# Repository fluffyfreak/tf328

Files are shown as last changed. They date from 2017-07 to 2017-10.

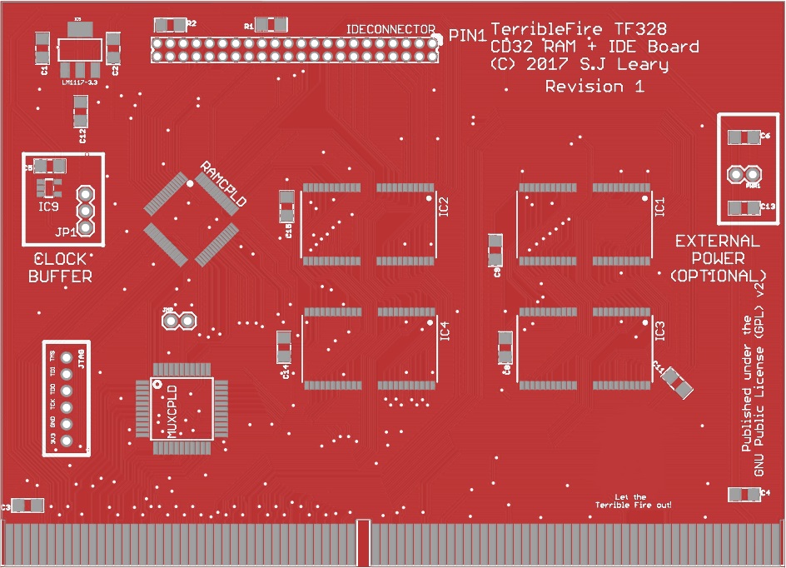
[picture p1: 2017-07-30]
docs/tf328_rev1.jpg

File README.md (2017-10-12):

# TF328 Revision 1

An 8mb Fast RAM + IDE Board for the CD32.

Known Issues: 

1. Your CF Card MUST be 3.3/5V tolerant as some of the control signals are 3.3V.

A prototype version was built and this contains all the lessons learned from that prototype. 

This repository contains all the files needed to produce a copy of my IDE+RAM board.

The CPLDs Required are 1 x XC9572XL-10VQ64 and 1 x XC9536XL-10VQG44C.  10ns "Commercial" version is fine.

Everything in this repository is released under the GNU GPLv2. You may create or base commercial PCBs from the work in this repository but you must make the sources for all derivative work available. I have noticed some forks have removed copyright notices. This is a breach of the GPL.

## Board Options

### Clock Buffer 

The clock buffer is a stabilty modification I added to buffer the clock due to slow rise times observed on other Amiga Hardware. It may not be required at all. If you decide not to add the clock buffer then you should jumper the middle pin of the CLOCKSEL jumper to the pin nearest the edge connector. If you wish to use the buffered clock you need to add IC9 and jumper the middle pin to the position nearest the IDE connector. If you wish to disable the board remove the jumper entirely.

### External Power

Jumper PWR1 is intended for use when bringing up the board so that the CPLDs can be programmed without inserting the card. It is not required after this unless you wish to use it to power other devices. 

### JMP Feature 

Jumper JMP is intended to trigger an NMI. This works via the MUXCPLD which detects the external pin being pulled HIGH and will pull IPL0-2 low until released. This feature is done synchronously to prevent glitches. It is intended for use with HRTMon. 

## Firmware / Requirements

  * Xilinx ISE, 14.7 (the final version - other versions may work but this is the one I support)
  * JTAG Adaptor

[For more information visit my channel](https://www.youtube.com/c/TerribleFire)

## License

This project and all the files contained are released under the GNU GPLv2. If you build a modified version of the board you must supply the end user with all the sources (this can be a web link).

# Bill of Materials

|Part | Value | Device | Package | Description |
|-----|---|---|---|---|
| R1 | 1K | RESISTOR1206 | 1206 | Resistors | 
| R2 | 1K | RESISTOR1206 | 1206 | Resistors | 
| C1 | 10uF | CAP_CERAMIC1206 | 1206 | Ceramic Capacitors | 
| C2 | 10uF | CAP_CERAMIC1206 | 1206 | Ceramic Capacitors | 
| C3 | 10uF | CAP_CERAMIC1206 | 1206 | Ceramic Capacitors | 
| C4 | 22uF | CAP_CERAMIC1206 | 1206 | Ceramic Capacitors | 
| C5 | 100nF | CAP_CERAMIC1206 | 1206 | Ceramic Capacitors | 
| C6 | 22uF | CAP_CERAMIC1206 | 1206 | Ceramic Capacitors | 
| C7 | 1uF | CAP_CERAMIC1206 | 1206 | Ceramic Capacitors | 
| C8 | 100nF | CAP_CERAMIC1206 | 1206 | Ceramic Capacitors | 
| C9 | 100nF | CAP_CERAMIC1206 | 1206 | Ceramic Capacitors | 
| C10 | 10uF | CAP_CERAMIC1206 | 1206 | Ceramic Capacitors | 
| C11 | 22uF | CAP_CERAMIC1206 | 1206 | Ceramic Capacitors | 
| C12 | 22uF | CAP_CERAMIC1206 | 1206 | Ceramic Capacitors | 
| C13 | 22uF | CAP_CERAMIC1206 | 1206 | Ceramic Capacitors | 
| C14 | 100nF | CAP_CERAMIC1206 | 1206 | Ceramic Capacitors | 
| C15 | 100nF | CAP_CERAMIC1206 | 1206 | Ceramic Capacitors | 
| C16 | 1uF | CC0603 | C0603 | CAPACITOR, European symbol | 
| IC1 | IS41C16100C | IS41C16100C | TSOP44(50)-II | |
| IC2 | IS41C16100C | IS41C16100C | TSOP44(50)-II | |
| IC3 | IS41C16100C | IS41C16100C | TSOP44(50)-II | |
| IC4 | IS41C16100C | IS41C16100C | TSOP44(50)-II | |
| IC5 | LM1117-3.3 | V_REG_LM1117SOT223 | SOT223 | Voltage Regulator LM1117 |
| IC9 | 74LVC1G17DBV | 74LVC1G17DBV | SOT23-5 | Single Schmitt-Trigger Buffer (Optional)| 
| JMP | Optional | JUMPER-2PTH | 1X02 | NMI Jumper | 
| JP1 | CLOCKSEL | JUMPER-3PTH | 1X03 | | 
| JTAG | JTAG | HEADER-1X6ROUND | 1X06_ROUND | PIN HEADER | 
| PWR1 | EXT5V | JUMPER-2PTH | 1X02 | Jumper | 
| MUXCPLD | XC9536XL-10VQG44C | XC9536XL-10VQG44C | SQFP-S-10X10-44 | xc9536_pc44 XC9500 In-System Programmable CPLD Family | 
| RAMCPLD | XC9572XL-10VQ64 | XC9572XL-10VQ64 | VQ64 |  
| IDECONNECTOR | 87758-4416 | 87758-4416 | 87758-4416 | 44 Pin - 2mm Dual Row Single Wafer, Vertical T/H HDR |

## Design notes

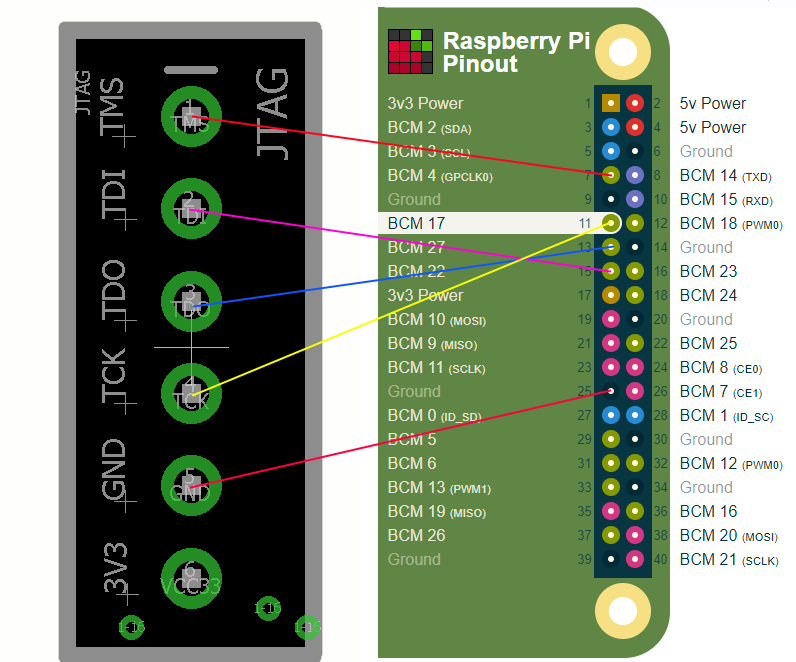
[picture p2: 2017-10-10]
docs/JTAG.png

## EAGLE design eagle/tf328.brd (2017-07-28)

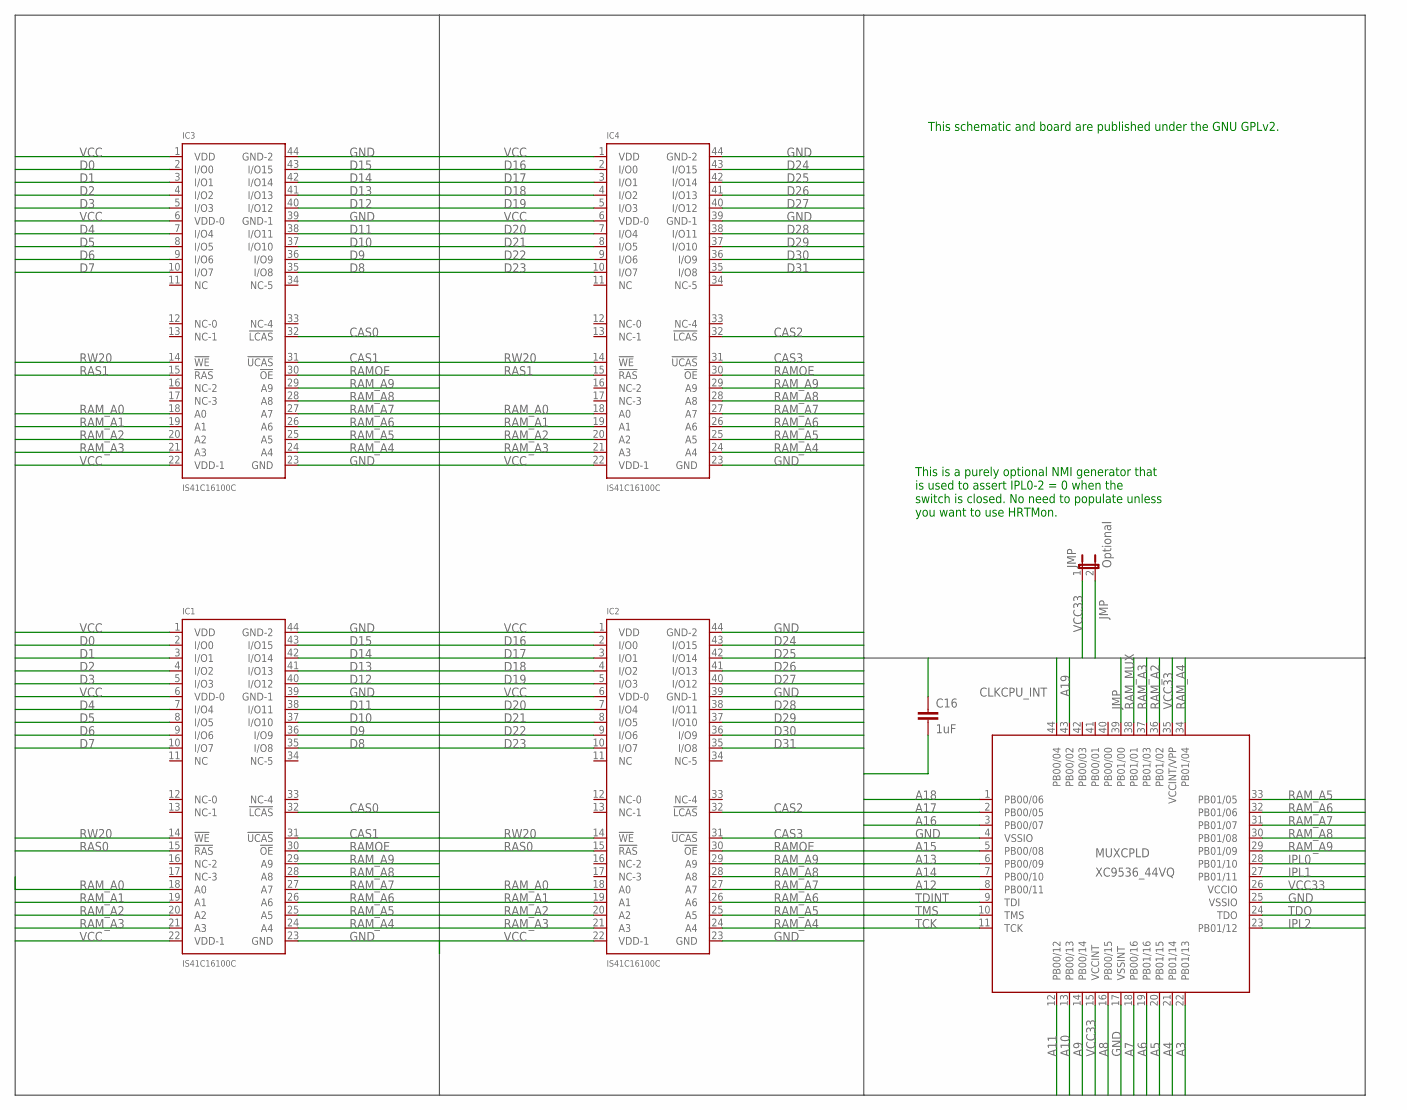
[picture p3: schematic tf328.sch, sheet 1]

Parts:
C16: 1uF; C0603
IC1, IC2, IC3, IC4: IS41C16100C; TSOP44(50)-II
JMP: Optional; 1X02
MUXCPLD: XC9536_44VQ; SQFP-S-10X10-44

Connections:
A3: MUXCPLD.22 (PB01/13); also elsewhere on the board
A4: MUXCPLD.21 (PB01/14); also elsewhere on the board
A5: MUXCPLD.20 (PB01/15); also elsewhere on the board
A6: MUXCPLD.19 (PB01/16); also elsewhere on the board
A7: MUXCPLD.18 (PB00/16); also elsewhere on the board
A8: MUXCPLD.16 (PB00/15); also elsewhere on the board
A9: MUXCPLD.14 (PB00/14); also elsewhere on the board
A10: MUXCPLD.13 (PB00/13); also elsewhere on the board
A11: MUXCPLD.12 (PB00/12); also elsewhere on the board
A12: MUXCPLD.8 (PB00/11); also elsewhere on the board
A13: MUXCPLD.6 (PB00/09); also elsewhere on the board
A14: MUXCPLD.7 (PB00/10); also elsewhere on the board
A15: MUXCPLD.5 (PB00/08); also elsewhere on the board
A16: MUXCPLD.3 (PB00/07); also elsewhere on the board
A17: MUXCPLD.2 (PB00/05); also elsewhere on the board
A18: MUXCPLD.1 (PB00/06); also elsewhere on the board
A19: MUXCPLD.43 (PB00/02); also elsewhere on the board
CAS0: IC1.32 (!LCAS), IC3.32 (!LCAS); also elsewhere on the board
CAS1: IC1.31 (!UCAS), IC3.31 (!UCAS); also elsewhere on the board
CAS2: IC2.32 (!LCAS), IC4.32 (!LCAS); also elsewhere on the board
CAS3: IC2.31 (!UCAS), IC4.31 (!UCAS); also elsewhere on the board
CLKCPU_INT: MUXCPLD.44 (PB00/04); also elsewhere on the board
D0: IC1.2 (I/O0), IC3.2 (I/O0); also elsewhere on the board
D1: IC1.3 (I/O1), IC3.3 (I/O1); also elsewhere on the board
D2: IC1.4 (I/O2), IC3.4 (I/O2); also elsewhere on the board
D3: IC1.5 (I/O3), IC3.5 (I/O3); also elsewhere on the board
D4: IC1.7 (I/O4), IC3.7 (I/O4); also elsewhere on the board
D5: IC1.8 (I/O5), IC3.8 (I/O5); also elsewhere on the board
D6: IC1.9 (I/O6), IC3.9 (I/O6); also elsewhere on the board
D7: IC1.10 (I/O7), IC3.10 (I/O7); also elsewhere on the board
D8: IC1.35 (I/O8), IC3.35 (I/O8); also elsewhere on the board
D9: IC1.36 (I/O9), IC3.36 (I/O9); also elsewhere on the board
D10: IC1.37 (I/O10), IC3.37 (I/O10); also elsewhere on the board
D11: IC1.38 (I/O11), IC3.38 (I/O11); also elsewhere on the board
D12: IC1.40 (I/O12), IC3.40 (I/O12); also elsewhere on the board
D13: IC1.41 (I/O13), IC3.41 (I/O13); also elsewhere on the board
D14: IC1.42 (I/O14), IC3.42 (I/O14); also elsewhere on the board
D15: IC1.43 (I/O15), IC3.43 (I/O15); also elsewhere on the board
D16: IC2.2 (I/O0), IC4.2 (I/O0); also elsewhere on the board
D17: IC2.3 (I/O1), IC4.3 (I/O1); also elsewhere on the board
D18: IC2.4 (I/O2), IC4.4 (I/O2); also elsewhere on the board
D19: IC2.5 (I/O3), IC4.5 (I/O3); also elsewhere on the board
D20: IC2.7 (I/O4), IC4.7 (I/O4); also elsewhere on the board
D21: IC2.8 (I/O5), IC4.8 (I/O5); also elsewhere on the board
D22: IC2.9 (I/O6), IC4.9 (I/O6); also elsewhere on the board
D23: IC2.10 (I/O7), IC4.10 (I/O7); also elsewhere on the board
D24: IC2.43 (I/O15), IC4.43 (I/O15); also elsewhere on the board
D25: IC2.42 (I/O14), IC4.42 (I/O14); also elsewhere on the board
D26: IC2.41 (I/O13), IC4.41 (I/O13); also elsewhere on the board
D27: IC2.40 (I/O12), IC4.40 (I/O12); also elsewhere on the board
D28: IC2.38 (I/O11), IC4.38 (I/O11); also elsewhere on the board
D29: IC2.37 (I/O10), IC4.37 (I/O10); also elsewhere on the board
D30: IC2.36 (I/O9), IC4.36 (I/O9); also elsewhere on the board
D31: IC2.35 (I/O8), IC4.35 (I/O8); also elsewhere on the board
GND: C16.2, IC1.23 (GND), IC1.39 (GND-1), IC1.44 (GND-2), IC2.23 (GND), IC2.39 (GND-1), IC2.44 (GND-2), IC3.23 (GND), IC3.39 (GND-1), IC3.44 (GND-2), IC4.23 (GND), IC4.39 (GND-1), IC4.44 (GND-2), MUXCPLD.4 (VSSIO), MUXCPLD.17 (VSSINT), MUXCPLD.25 (VSSIO); also elsewhere on the board
IPL0: MUXCPLD.28 (PB01/10); also elsewhere on the board
IPL1: MUXCPLD.27 (PB01/11); also elsewhere on the board
IPL2: MUXCPLD.23 (PB01/12); also elsewhere on the board
JMP: JMP.2, MUXCPLD.39 (PB01/00)
RAMOE: IC1.30 (!OE), IC2.30 (!OE), IC3.30 (!OE), IC4.30 (!OE); also elsewhere on the board
RAM_A0: IC1.18 (A0), IC2.18 (A0), IC3.18 (A0), IC4.18 (A0); also elsewhere on the board
RAM_A1: IC1.19 (A1), IC2.19 (A1), IC3.19 (A1), IC4.19 (A1); also elsewhere on the board
RAM_A2: IC1.20 (A2), IC2.20 (A2), IC3.20 (A2), IC4.20 (A2), MUXCPLD.36 (PB01/02)
RAM_A3: IC1.21 (A3), IC2.21 (A3), IC3.21 (A3), IC4.21 (A3), MUXCPLD.37 (PB01/03)
RAM_A4: IC1.24 (A4), IC2.24 (A4), IC3.24 (A4), IC4.24 (A4), MUXCPLD.34 (PB01/04)
RAM_A5: IC1.25 (A5), IC2.25 (A5), IC3.25 (A5), IC4.25 (A5), MUXCPLD.33 (PB01/05)
RAM_A6: IC1.26 (A6), IC2.26 (A6), IC3.26 (A6), IC4.26 (A6), MUXCPLD.32 (PB01/06)
RAM_A7: IC1.27 (A7), IC2.27 (A7), IC3.27 (A7), IC4.27 (A7), MUXCPLD.31 (PB01/07)
RAM_A8: IC1.28 (A8), IC2.28 (A8), IC3.28 (A8), IC4.28 (A8), MUXCPLD.30 (PB01/08)
RAM_A9: IC1.29 (A9), IC2.29 (A9), IC3.29 (A9), IC4.29 (A9), MUXCPLD.29 (PB01/09)
RAM_MUX: MUXCPLD.38 (PB01/01); also elsewhere on the board
RAS0: IC1.15 (!RAS), IC2.15 (!RAS); also elsewhere on the board
RAS1: IC3.15 (!RAS), IC4.15 (!RAS); also elsewhere on the board
RW20: IC1.14 (!WE), IC2.14 (!WE), IC3.14 (!WE), IC4.14 (!WE); also elsewhere on the board
TCK: MUXCPLD.11 (TCK); also elsewhere on the board
TDINT: MUXCPLD.9 (TDI); also elsewhere on the board
TDO: MUXCPLD.24 (TDO); also elsewhere on the board
TMS: MUXCPLD.10 (TMS); also elsewhere on the board
VCC: IC1.1 (VDD), IC1.6 (VDD-0), IC1.22 (VDD-1), IC2.1 (VDD), IC2.6 (VDD-0), IC2.22 (VDD-1), IC3.1 (VDD), IC3.6 (VDD-0), IC3.22 (VDD-1), IC4.1 (VDD), IC4.6 (VDD-0), IC4.22 (VDD-1); also elsewhere on the board
VCC33: C16.1, JMP.1, MUXCPLD.15 (VCCINT), MUXCPLD.26 (VCCIO), MUXCPLD.35 (VCCINT/VPP); also elsewhere on the board

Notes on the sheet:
This is a purely optional NMI generator that is used to assert IPL0-2 = 0 when the switch is closed. No need to populate unless you want to use HRTMon.
This schematic and board are published under the GNU GPLv2.

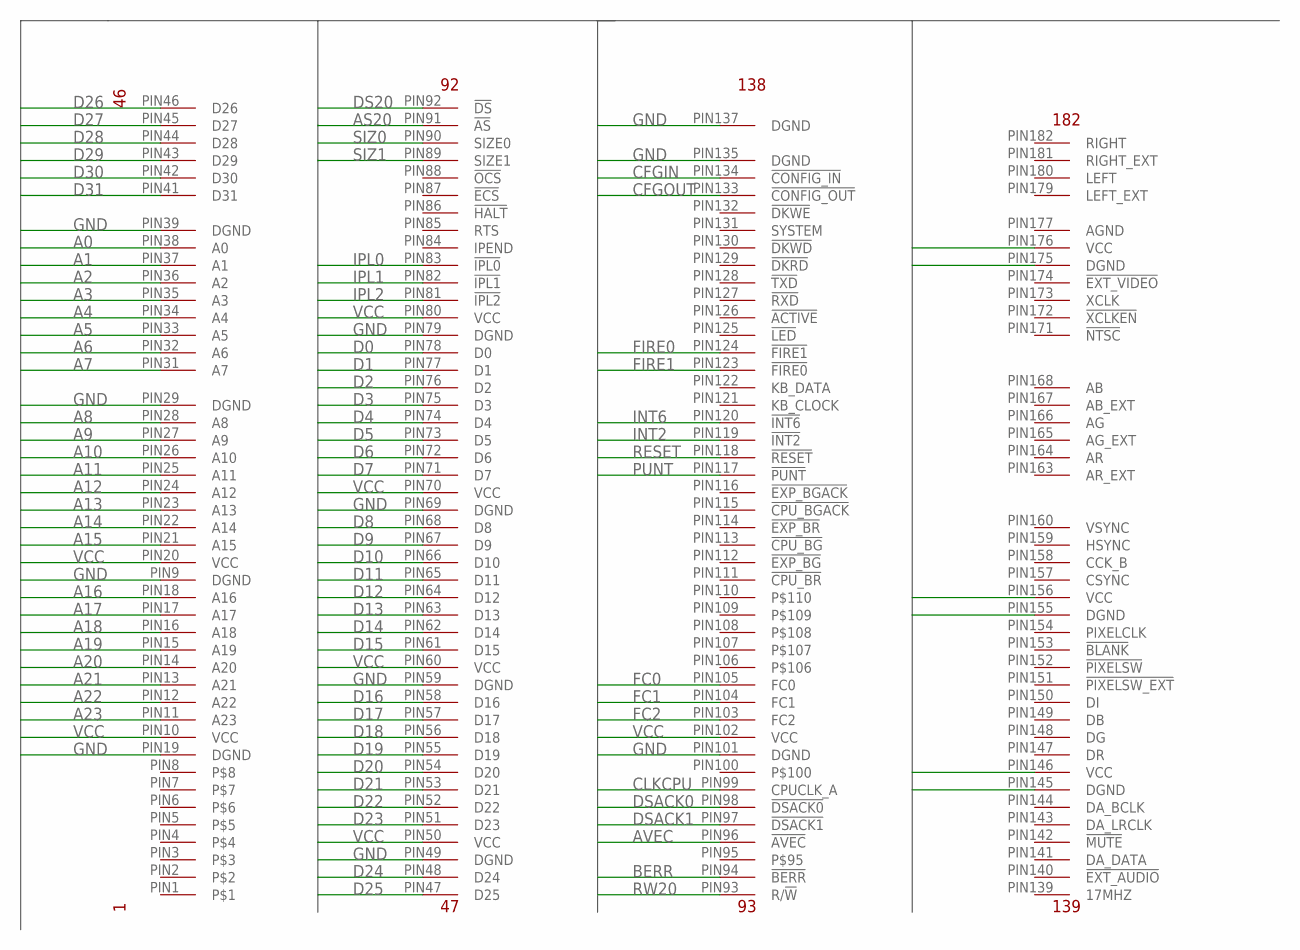
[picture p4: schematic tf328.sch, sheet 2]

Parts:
CONN1: MCA_CONN_182

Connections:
A0: CONN1.PIN38 (A0); also elsewhere on the board
A1: CONN1.PIN37 (A1); also elsewhere on the board
A2: CONN1.PIN36 (A2); also elsewhere on the board
A3: CONN1.PIN35 (A3); also elsewhere on the board
A4: CONN1.PIN34 (A4); also elsewhere on the board
A5: CONN1.PIN33 (A5); also elsewhere on the board
A6: CONN1.PIN32 (A6); also elsewhere on the board
A7: CONN1.PIN31 (A7); also elsewhere on the board
A8: CONN1.PIN28 (A8); also elsewhere on the board
A9: CONN1.PIN27 (A9); also elsewhere on the board
A10: CONN1.PIN26 (A10); also elsewhere on the board
A11: CONN1.PIN25 (A11); also elsewhere on the board
A12: CONN1.PIN24 (A12); also elsewhere on the board
A13: CONN1.PIN23 (A13); also elsewhere on the board
A14: CONN1.PIN22 (A14); also elsewhere on the board
A15: CONN1.PIN21 (A15); also elsewhere on the board
A16: CONN1.PIN18 (A16); also elsewhere on the board
A17: CONN1.PIN17 (A17); also elsewhere on the board
A18: CONN1.PIN16 (A18); also elsewhere on the board
A19: CONN1.PIN15 (A19); also elsewhere on the board
A20: CONN1.PIN14 (A20); also elsewhere on the board
A21: CONN1.PIN13 (A21); also elsewhere on the board
A22: CONN1.PIN12 (A22); also elsewhere on the board
A23: CONN1.PIN11 (A23); also elsewhere on the board
AGND: CONN1.PIN177 (AGND)
AS20: CONN1.PIN91 (!AS); also elsewhere on the board
AVEC: CONN1.PIN96 (!AVEC)
BERR: CONN1.PIN94 (!BERR)
CFGIN: CONN1.PIN134 (!CONFIG_IN)
CFGOUT: CONN1.PIN133 (!CONFIG_OUT)
CLKCPU: CONN1.PIN99 (CPUCLK_A); also elsewhere on the board
D0: CONN1.PIN78 (D0); also elsewhere on the board
D1: CONN1.PIN77 (D1); also elsewhere on the board
D2: CONN1.PIN76 (D2); also elsewhere on the board
D3: CONN1.PIN75 (D3); also elsewhere on the board
D4: CONN1.PIN74 (D4); also elsewhere on the board
D5: CONN1.PIN73 (D5); also elsewhere on the board
D6: CONN1.PIN72 (D6); also elsewhere on the board
D7: CONN1.PIN71 (D7); also elsewhere on the board
D8: CONN1.PIN68 (D8); also elsewhere on the board
D9: CONN1.PIN67 (D9); also elsewhere on the board
D10: CONN1.PIN66 (D10); also elsewhere on the board
D11: CONN1.PIN65 (D11); also elsewhere on the board
D12: CONN1.PIN64 (D12); also elsewhere on the board
D13: CONN1.PIN63 (D13); also elsewhere on the board
D14: CONN1.PIN62 (D14); also elsewhere on the board
D15: CONN1.PIN61 (D15); also elsewhere on the board
D16: CONN1.PIN58 (D16); also elsewhere on the board
D17: CONN1.PIN57 (D17); also elsewhere on the board
D18: CONN1.PIN56 (D18); also elsewhere on the board
D19: CONN1.PIN55 (D19); also elsewhere on the board
D20: CONN1.PIN54 (D20); also elsewhere on the board
D21: CONN1.PIN53 (D21); also elsewhere on the board
D22: CONN1.PIN52 (D22); also elsewhere on the board
D23: CONN1.PIN51 (D23); also elsewhere on the board
D24: CONN1.PIN48 (D24); also elsewhere on the board
D25: CONN1.PIN47 (D25); also elsewhere on the board
D26: CONN1.PIN46 (D26); also elsewhere on the board
D27: CONN1.PIN45 (D27); also elsewhere on the board
D28: CONN1.PIN44 (D28); also elsewhere on the board
D29: CONN1.PIN43 (D29); also elsewhere on the board
D30: CONN1.PIN42 (D30); also elsewhere on the board
D31: CONN1.PIN41 (D31); also elsewhere on the board
DS20: CONN1.PIN92 (!DS); also elsewhere on the board
DSACK0: CONN1.PIN98 (!DSACK0); also elsewhere on the board
DSACK1: CONN1.PIN97 (!DSACK1); also elsewhere on the board
FC0: CONN1.PIN105 (FC0)
FC1: CONN1.PIN104 (FC1)
FC2: CONN1.PIN103 (FC2)
FIRE0: CONN1.PIN124 (!FIRE1)
FIRE1: CONN1.PIN123 (!FIRE0)
GND: CONN1.PIN9 (DGND), CONN1.PIN19 (DGND), CONN1.PIN29 (DGND), CONN1.PIN39 (DGND), CONN1.PIN49 (DGND), CONN1.PIN59 (DGND), CONN1.PIN69 (DGND), CONN1.PIN79 (DGND), CONN1.PIN101 (DGND), CONN1.PIN135 (DGND), CONN1.PIN137 (DGND), CONN1.PIN145 (DGND), CONN1.PIN155 (DGND), CONN1.PIN175 (DGND); also elsewhere on the board
INT2: CONN1.PIN119 (!INT2); also elsewhere on the board
INT6: CONN1.PIN120 (!INT6)
IPL0: CONN1.PIN83 (!IPL0); also elsewhere on the board
IPL1: CONN1.PIN82 (!IPL1); also elsewhere on the board
IPL2: CONN1.PIN81 (!IPL2); also elsewhere on the board
PUNT: CONN1.PIN117 (!PUNT); also elsewhere on the board
RESET: CONN1.PIN118 (!RESET); also elsewhere on the board
RW20: CONN1.PIN93 (R/!W); also elsewhere on the board
SIZ0: CONN1.PIN90 (SIZE0); also elsewhere on the board
SIZ1: CONN1.PIN89 (SIZE1); also elsewhere on the board
VCC: CONN1.PIN10 (VCC), CONN1.PIN20 (VCC), CONN1.PIN50 (VCC), CONN1.PIN60 (VCC), CONN1.PIN70 (VCC), CONN1.PIN80 (VCC), CONN1.PIN102 (VCC), CONN1.PIN146 (VCC), CONN1.PIN156 (VCC), CONN1.PIN176 (VCC); also elsewhere on the board

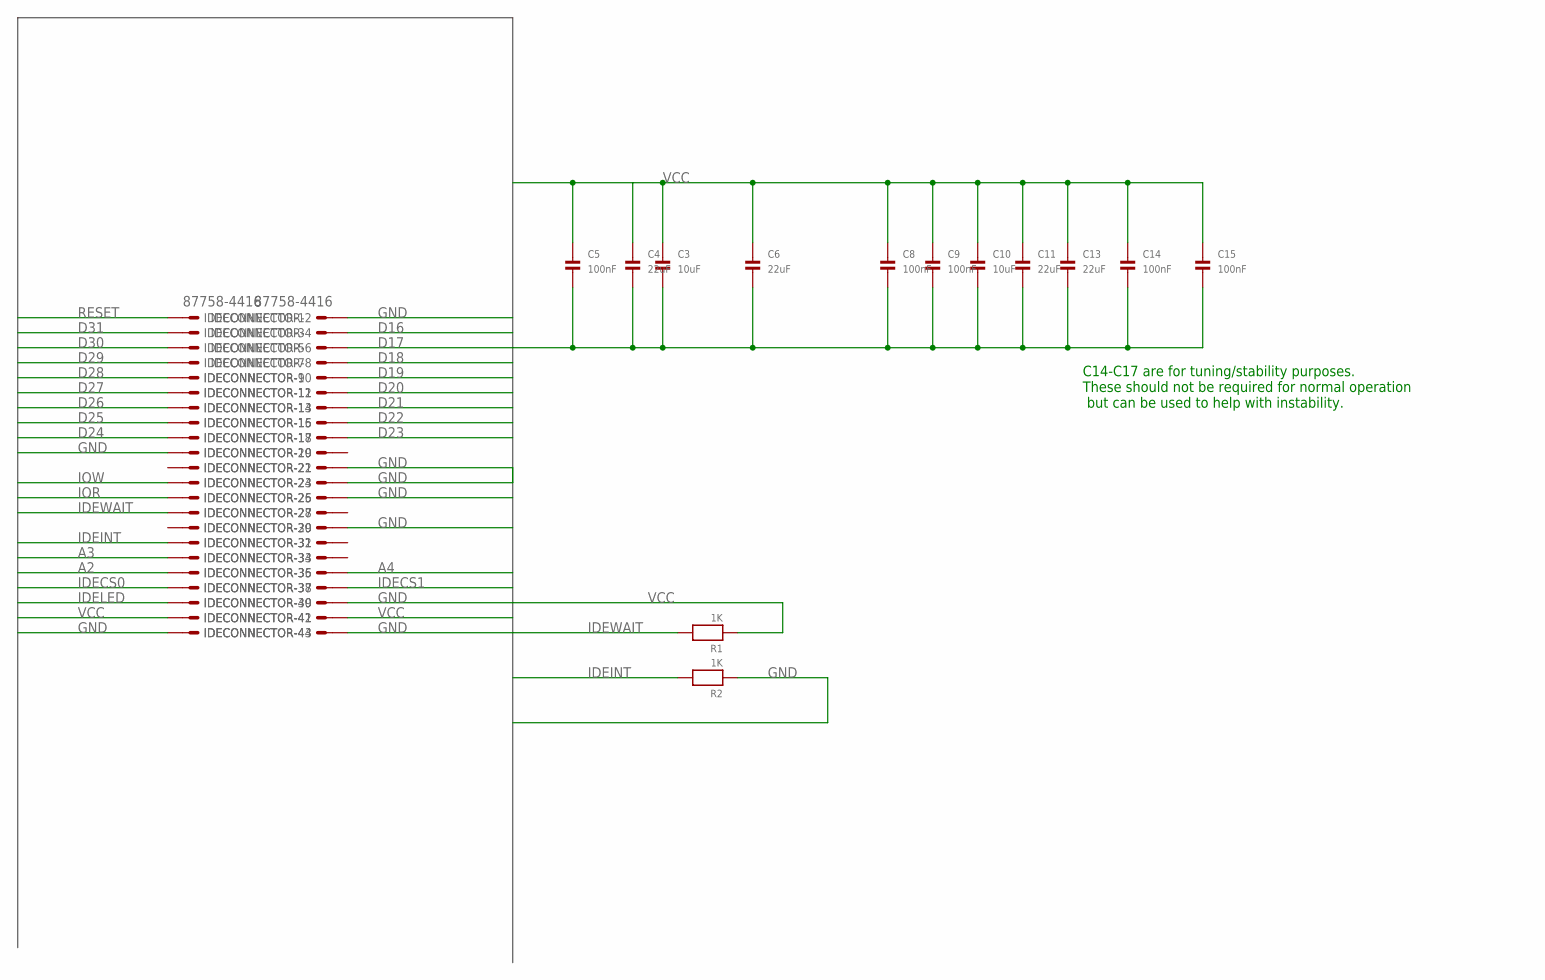
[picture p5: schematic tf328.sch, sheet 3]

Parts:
C3, C10: 10uF; 1206
C4, C6, C11, C13: 22uF; 1206
C5, C8, C9, C14, C15: 100nF; 1206
IDECONNECTOR: 87758-4416
R1, R2: 1K; 1206

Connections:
A2: IDECONNECTOR.35; also elsewhere on the board
A3: IDECONNECTOR.33; also elsewhere on the board
A4: IDECONNECTOR.36; also elsewhere on the board
D16: IDECONNECTOR.4; also elsewhere on the board
D17: IDECONNECTOR.6; also elsewhere on the board
D18: IDECONNECTOR.8; also elsewhere on the board
D19: IDECONNECTOR.10; also elsewhere on the board
D20: IDECONNECTOR.12; also elsewhere on the board
D21: IDECONNECTOR.14; also elsewhere on the board
D22: IDECONNECTOR.16; also elsewhere on the board
D23: IDECONNECTOR.18; also elsewhere on the board
D24: IDECONNECTOR.17; also elsewhere on the board
D25: IDECONNECTOR.15; also elsewhere on the board
D26: IDECONNECTOR.13; also elsewhere on the board
D27: IDECONNECTOR.11; also elsewhere on the board
D28: IDECONNECTOR.9; also elsewhere on the board
D29: IDECONNECTOR.7; also elsewhere on the board
D30: IDECONNECTOR.5; also elsewhere on the board
D31: IDECONNECTOR.3; also elsewhere on the board
GND: C3.2, C4.2, C5.2, C6.2, C8.2, C9.2, C10.2, C11.2, C13.2, C14.2, C15.2, IDECONNECTOR.2, IDECONNECTOR.19, IDECONNECTOR.22, IDECONNECTOR.24, IDECONNECTOR.26, IDECONNECTOR.30, IDECONNECTOR.40, IDECONNECTOR.43, IDECONNECTOR.44, R2.1; also elsewhere on the board
IDECS0: IDECONNECTOR.37; also elsewhere on the board
IDECS1: IDECONNECTOR.38; also elsewhere on the board
IDEINT: IDECONNECTOR.31, R2.2; also elsewhere on the board
IDELED: IDECONNECTOR.39
IDEWAIT: IDECONNECTOR.27, R1.2
IOR: IDECONNECTOR.25; also elsewhere on the board
IOW: IDECONNECTOR.23; also elsewhere on the board
RESET: IDECONNECTOR.1; also elsewhere on the board
VCC: C3.1, C4.1, C5.1, C6.1, C8.1, C9.1, C10.1, C11.1, C13.1, C14.1, C15.1, IDECONNECTOR.41, IDECONNECTOR.42, R1.1; also elsewhere on the board

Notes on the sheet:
C14-C17 are for tuning/stability purposes. These should not be required for normal operation but can be used to help with instability.

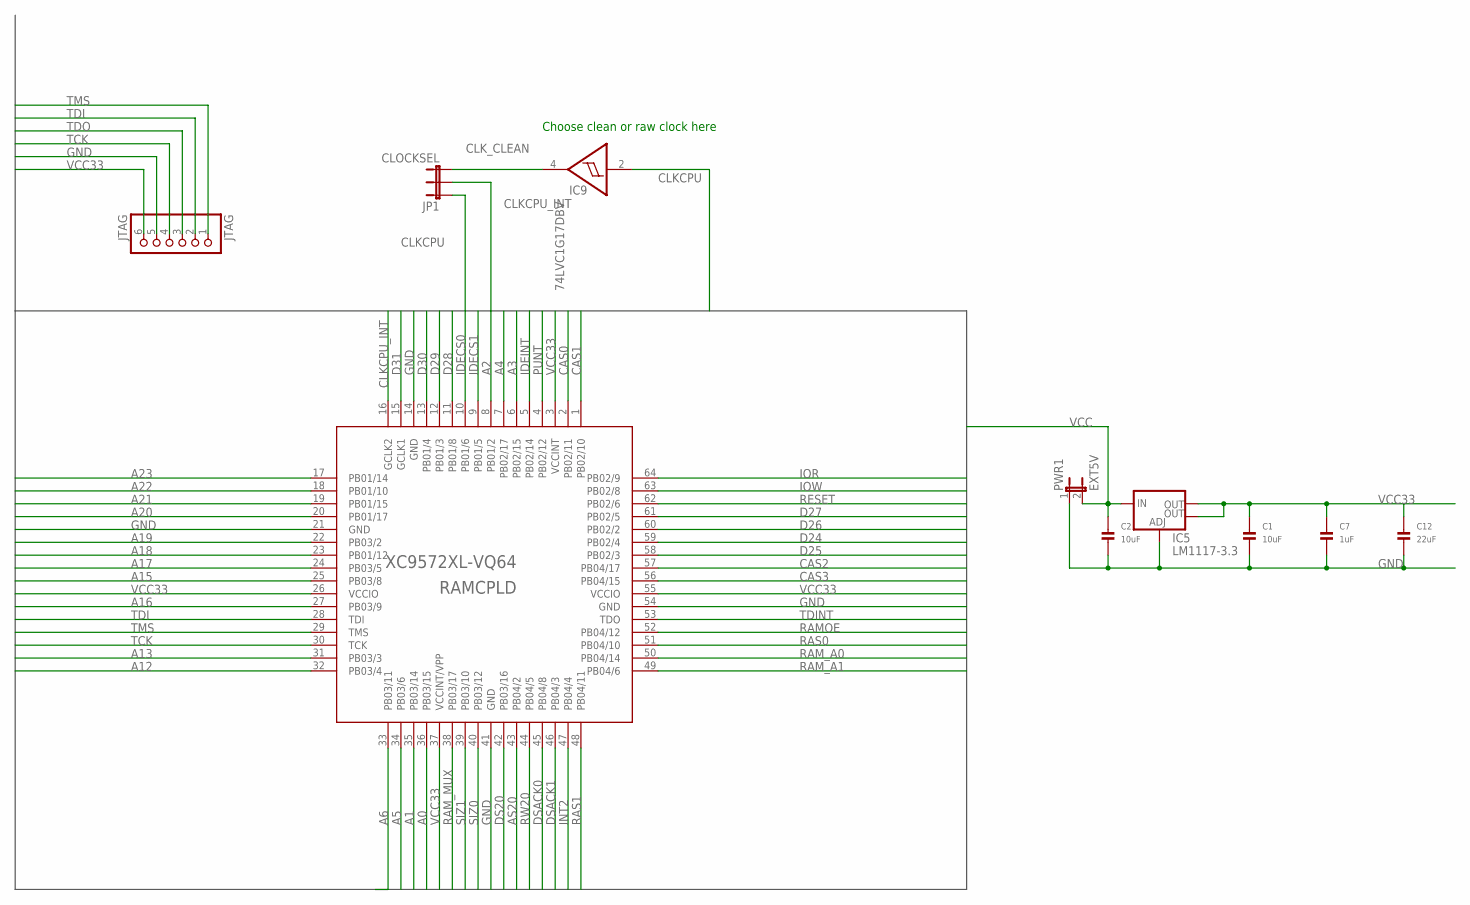
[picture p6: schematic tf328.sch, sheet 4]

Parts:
C1, C2: 10uF; 1206
C7: 1uF; 1206
C12: 22uF; 1206
IC5: LM1117-3.3; SOT223
IC9: 74LVC1G17DBV; SOT23-5
JP1: CLOCKSEL; 1X03
JTAG: JTAG; 1X06_ROUND
PWR1: EXT5V; 1X02
RAMCPLD: XC9572XL-VQ64; VQ64

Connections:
A0: RAMCPLD.36 (PB03/15); also elsewhere on the board
A1: RAMCPLD.35 (PB03/14); also elsewhere on the board
A2: RAMCPLD.8 (PB01/2); also elsewhere on the board
A3: RAMCPLD.6 (PB02/15); also elsewhere on the board
A4: RAMCPLD.7 (PB02/17); also elsewhere on the board
A5: RAMCPLD.34 (PB03/6); also elsewhere on the board
A6: RAMCPLD.33 (PB03/11); also elsewhere on the board
A12: RAMCPLD.32 (PB03/4); also elsewhere on the board
A13: RAMCPLD.31 (PB03/3); also elsewhere on the board
A15: RAMCPLD.25 (PB03/8); also elsewhere on the board
A16: RAMCPLD.27 (PB03/9); also elsewhere on the board
A17: RAMCPLD.24 (PB03/5); also elsewhere on the board
A18: RAMCPLD.23 (PB01/12); also elsewhere on the board
A19: RAMCPLD.22 (PB03/2); also elsewhere on the board
A20: RAMCPLD.20 (PB01/17); also elsewhere on the board
A21: RAMCPLD.19 (PB01/15); also elsewhere on the board
A22: RAMCPLD.18 (PB01/10); also elsewhere on the board
A23: RAMCPLD.17 (PB01/14); also elsewhere on the board
AS20: RAMCPLD.43 (PB04/2); also elsewhere on the board
CAS0: RAMCPLD.2 (PB02/11); also elsewhere on the board
CAS1: RAMCPLD.1 (PB02/10); also elsewhere on the board
CAS2: RAMCPLD.57 (PB04/17); also elsewhere on the board
CAS3: RAMCPLD.56 (PB04/15); also elsewhere on the board
CLKCPU: IC9.2 (I), JP1.1; also elsewhere on the board
CLKCPU_INT: JP1.2, RAMCPLD.16 (GCLK2); also elsewhere on the board
CLK_CLEAN: IC9.4 (O), JP1.3
D24: RAMCPLD.59 (PB02/4); also elsewhere on the board
D25: RAMCPLD.58 (PB02/3); also elsewhere on the board
D26: RAMCPLD.60 (PB02/2); also elsewhere on the board
D27: RAMCPLD.61 (PB02/5); also elsewhere on the board
D28: RAMCPLD.11 (PB01/8); also elsewhere on the board
D29: RAMCPLD.12 (PB01/3); also elsewhere on the board
D30: RAMCPLD.13 (PB01/4); also elsewhere on the board
D31: RAMCPLD.15 (GCLK1); also elsewhere on the board
DS20: RAMCPLD.42 (PB03/16); also elsewhere on the board
DSACK0: RAMCPLD.45 (PB04/8); also elsewhere on the board
DSACK1: RAMCPLD.46 (PB04/3); also elsewhere on the board
GND: C1.2, C2.2, C7.2, C12.2, IC5.1 (ADJ), IC9.3 (GND), JTAG.5, PWR1.1, RAMCPLD.14 (GND), RAMCPLD.21 (GND), RAMCPLD.41 (GND), RAMCPLD.54 (GND); also elsewhere on the board
IDECS0: RAMCPLD.10 (PB01/6); also elsewhere on the board
IDECS1: RAMCPLD.9 (PB01/5); also elsewhere on the board
IDEINT: RAMCPLD.5 (PB02/14); also elsewhere on the board
INT2: RAMCPLD.47 (PB04/4); also elsewhere on the board
IOR: RAMCPLD.64 (PB02/9); also elsewhere on the board
IOW: RAMCPLD.63 (PB02/8); also elsewhere on the board
PUNT: RAMCPLD.4 (PB02/12); also elsewhere on the board
RAMOE: RAMCPLD.52 (PB04/12); also elsewhere on the board
RAM_A0: RAMCPLD.50 (PB04/14); also elsewhere on the board
RAM_A1: RAMCPLD.49 (PB04/6); also elsewhere on the board
RAM_MUX: RAMCPLD.38 (PB03/17); also elsewhere on the board
RAS0: RAMCPLD.51 (PB04/10); also elsewhere on the board
RAS1: RAMCPLD.48 (PB04/11); also elsewhere on the board
RESET: RAMCPLD.62 (PB02/6); also elsewhere on the board
RW20: RAMCPLD.44 (PB04/5); also elsewhere on the board
SIZ0: RAMCPLD.40 (PB03/12); also elsewhere on the board
SIZ1: RAMCPLD.39 (PB03/10); also elsewhere on the board
TCK: JTAG.4, RAMCPLD.30 (TCK); also elsewhere on the board
TDI: JTAG.2, RAMCPLD.28 (TDI)
TDINT: RAMCPLD.53 (TDO); also elsewhere on the board
TDO: JTAG.3; also elsewhere on the board
TMS: JTAG.1, RAMCPLD.29 (TMS); also elsewhere on the board
VCC: C2.1, IC5.3 (IN), IC9.5 (VCC), PWR1.2; also elsewhere on the board
VCC33: C1.1, C7.1, C12.1, IC5.2 (OUT), IC5.4 (OUT), JTAG.6, RAMCPLD.3 (VCCINT), RAMCPLD.26 (VCCIO), RAMCPLD.37 (VCCINT/VPP), RAMCPLD.55 (VCCIO); also elsewhere on the board

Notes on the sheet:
Choose clean or raw clock here

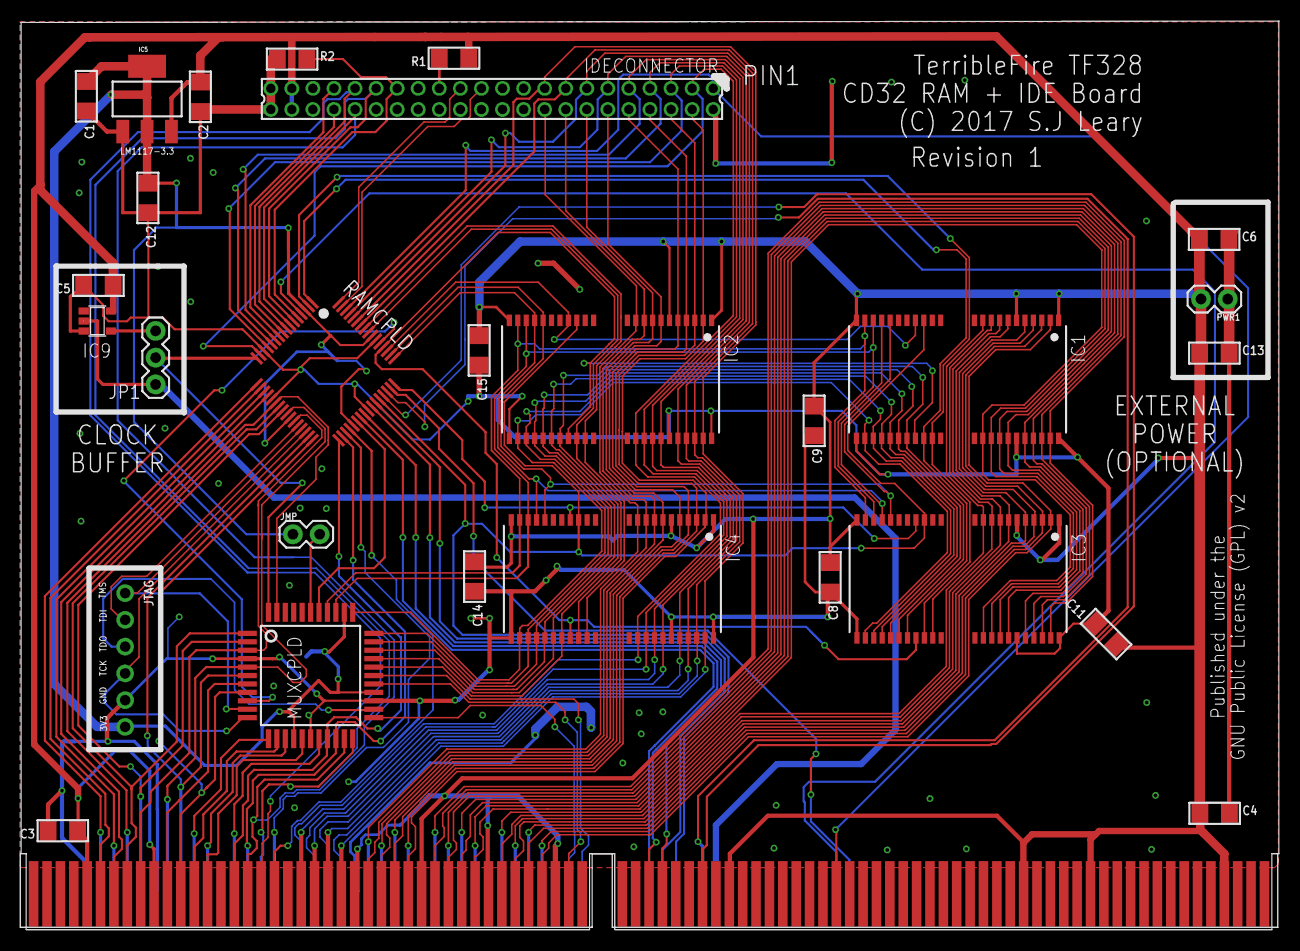
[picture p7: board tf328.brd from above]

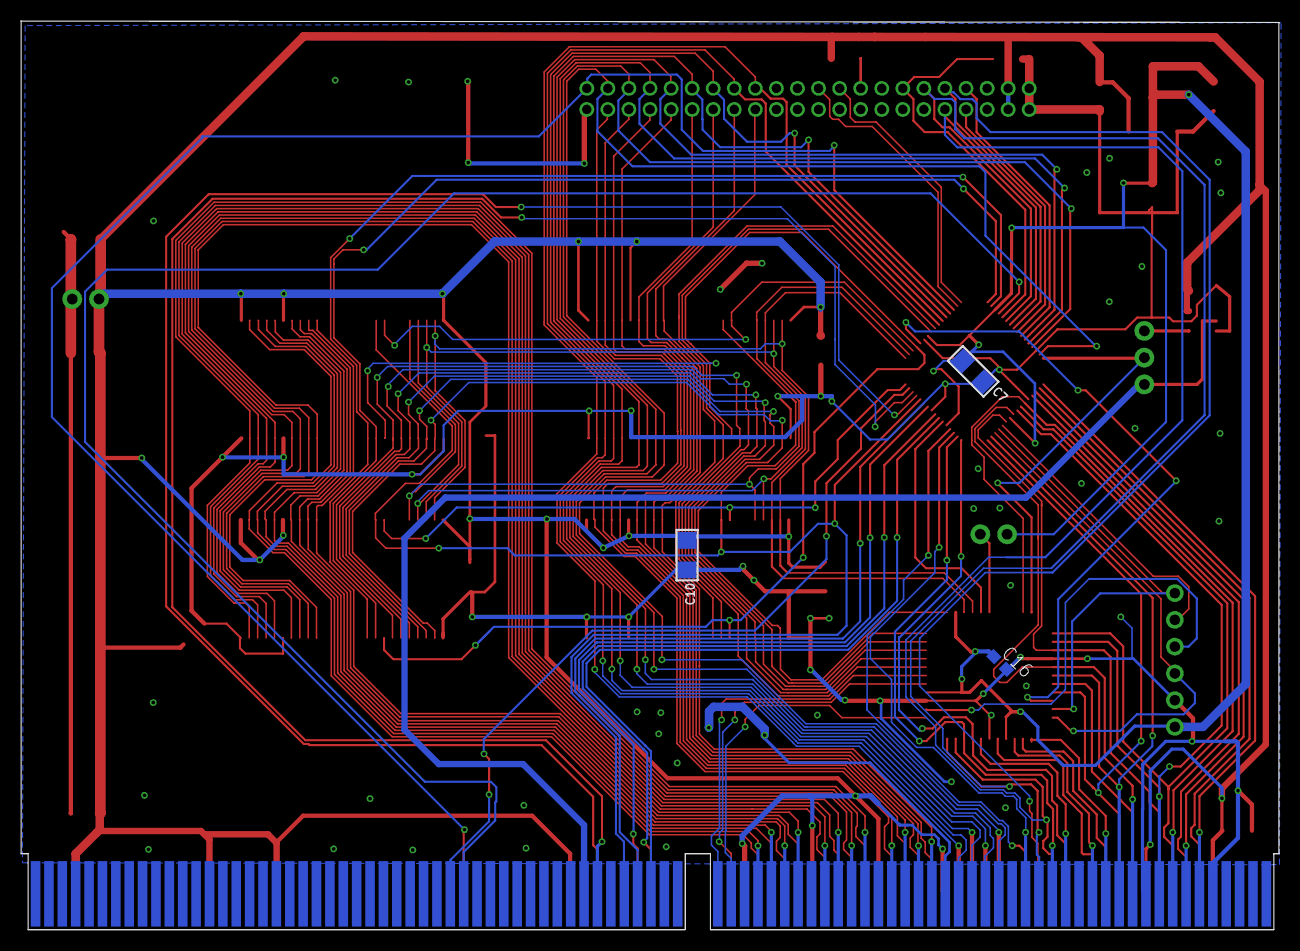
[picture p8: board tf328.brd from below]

Board: 2 copper layers, 119.4 x 86.3 mm, 32 parts (3 on the bottom side), 105 nets.

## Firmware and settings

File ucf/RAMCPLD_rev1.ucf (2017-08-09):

# Copyright (C) 2016-2017, Stephen J. Leary
# All rights reserved.
#
# This file is part of TF530 (Terrible Fire 030 Accelerator)
#
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
NET "A<0>"      LOC="36";
NET "A<1>"      LOC="35";
NET "A<2>"      LOC="8";
NET "A<3>"      LOC="6";
NET "A<4>"      LOC="7";
NET "A<5>"      LOC="34";
NET "A<6>"      LOC="33";
NET "A<12>"      LOC="32";
NET "A<13>"      LOC="31";
NET "A<15>"      LOC="25";
NET "A<16>"      LOC="27";
NET "A<17>"      LOC="24";
NET "A<18>"      LOC="23";
NET "A<19>"      LOC="22";
NET "A<20>"      LOC="20";
NET "A<21>"      LOC="19";
NET "A<22>"      LOC="18";
NET "A<23>"      LOC="17";
NET "AS20"      LOC="43";
NET "CAS<0>"      LOC="2";
NET "CAS<1>"      LOC="1";
NET "CAS<2>"      LOC="57";
NET "CAS<3>"      LOC="56";
NET "CLKCPU"      LOC="16";
NET "D<0>"      LOC="59";
NET "D<1>"      LOC="58";
NET "D<2>"      LOC="60";
NET "D<3>"      LOC="61";
NET "D<4>"      LOC="11";
NET "D<5>"      LOC="12";
NET "D<6>"      LOC="13";
NET "D<7>"      LOC="15";
NET "DS20"      LOC="42";
NET "DSACK<0>"      LOC="45";
NET "DSACK<1>"      LOC="46";
NET "IDECS<0>"      LOC="10";
NET "IDECS<1>"      LOC="9";
NET "IDEINT"      LOC="5";
NET "INT2"      LOC="47";
NET "IOR"      LOC="64";
NET "IOW"      LOC="63";
NET "PUNT"      LOC="4";
NET "RAMOE"      LOC="52";
NET "RAM_A<0>"      LOC="50";
NET "RAM_A<1>"      LOC="49";
NET "RAM_MUX"      LOC="38";
NET "RAS<0>"      LOC="51";
NET "RAS<1>"      LOC="48";
NET "RESET"      LOC="62";
NET "RW20"      LOC="44";
NET "SIZ<0>"      LOC="40";
NET "SIZ<1>"      LOC="39";

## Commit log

2017-07-28 Initial commit of the board.
    [tf328.brd, tf328.sch]
2017-07-30 Adding an image of the board
2017-10-02 Idea i had to make the board be disabled if the clock is not present. Hold everything in POR mode until i see three clock edges.
2017-10-07 new timer changes.
2017-10-07 updating the firmware with the refresh timer.
2017-10-08 Commiting the refresh timer firmware

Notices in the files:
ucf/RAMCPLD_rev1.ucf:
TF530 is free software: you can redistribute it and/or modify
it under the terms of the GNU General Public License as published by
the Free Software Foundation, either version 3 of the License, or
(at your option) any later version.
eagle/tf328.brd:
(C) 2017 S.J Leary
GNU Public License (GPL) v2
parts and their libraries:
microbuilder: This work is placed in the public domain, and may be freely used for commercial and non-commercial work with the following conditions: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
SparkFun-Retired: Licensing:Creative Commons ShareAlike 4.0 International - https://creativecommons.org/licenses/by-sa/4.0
